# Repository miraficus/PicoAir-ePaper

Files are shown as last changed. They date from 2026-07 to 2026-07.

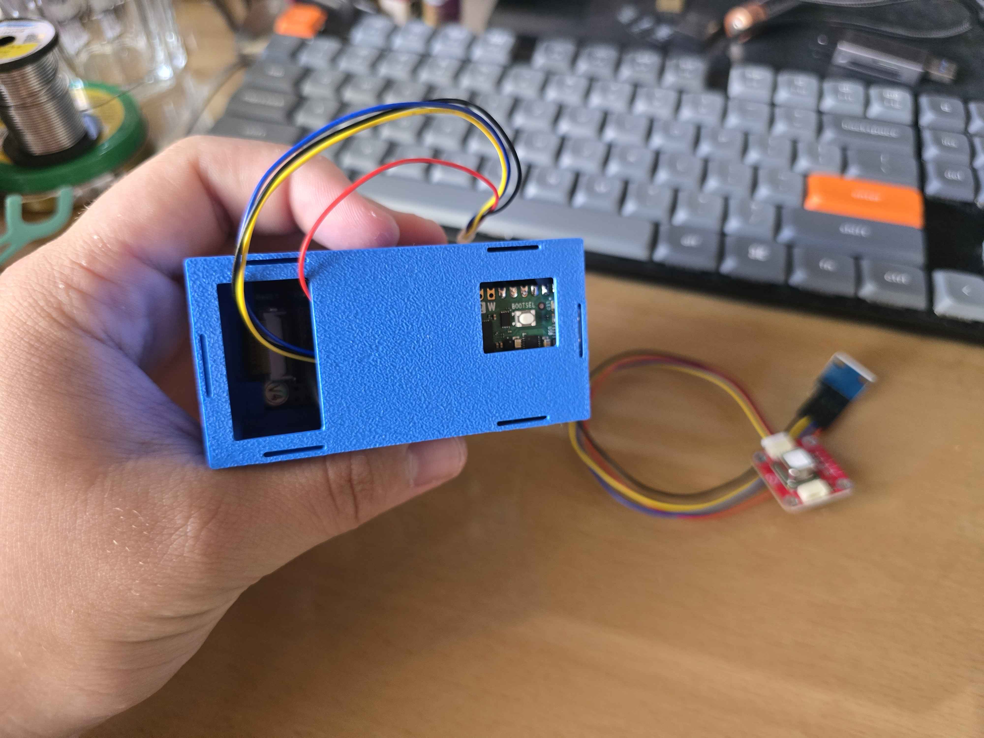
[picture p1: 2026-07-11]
photos/withmiddlecase.jpg

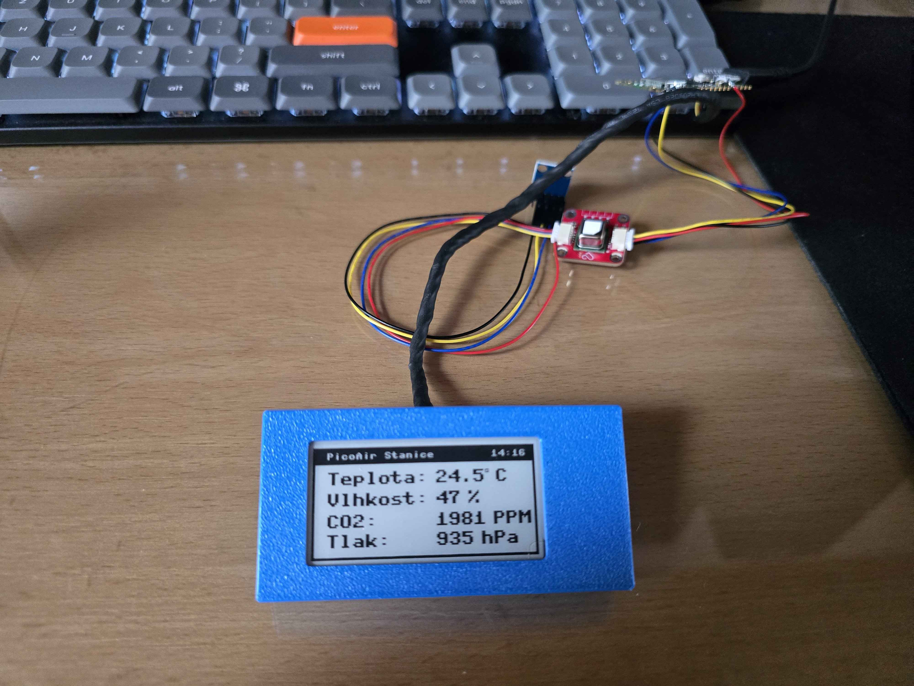
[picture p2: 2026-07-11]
photos/outside.jpg

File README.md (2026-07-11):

# PicoAir-ePaper
[WIP] Pi Pico based device with ePaper display to show temperature, humidity, ppm, time and pressure.

---

# 🍃 PicoAir ePaper Station

Moderní, energeticky úsporná meteostanice a monitor kvality vzduchu v interiéru postavená na mikrokontroléru **Raspberry Pi Pico W**. Stanice měří teplotu, vlhkost, koncentraci CO₂ a atmosférický tlak. Naměřená data zobrazuje na elegantním e-ink (e-paper) displeji a zároveň je v reálném čase odesílá přes Wi-Fi do databáze **InfluxDB** pro vizualizaci v **Grafaně**.

---

## ✨ Hlavní vlastnosti
- **Komplexní měření:** Sledování klíčových parametrů vzduchu (Teplota, Vlhkost, CO₂ v PPM, Tlak v hPa).
- **Sdílená I2C sběrnice:** Efektivní paralelní zapojení více senzorů na piny GP18/GP19.
- **e-Paper Displej:** Nízká spotřeba, perfektní čitelnost na slunci a nativní softwarová rotace obrazu na šířku.
- **Wi-Fi a NTP synchronizace:** Automatické nastavení přesného času z internetu s vestavěnou detekcí a přepínáním letního/zimního času (DST).
- **Direct InfluxDB logování:** Odesílání dat přímo z Pica do databáze pomocí HTTP Line Protocolu bez nutnosti mezistupňů.
- **Úsporný režim:** Kompletní odpojování a hluboký spánek Wi-Fi modulu i displeje mezi měřeními pro šetření baterie.

---

## 🛠️ Hardwarové komponenty
1. **[Raspberry Pi Pico W](https://rpishop.cz/554053/raspberry-pi-pico-2-w/)** (mikrokontrolér s Wi-Fi) [209 CZK]
2. **[Sensirion SCD41](https://www.laskakit.cz/laskakit-scd41-senzor-co2--teploty-a-vlhkosti-vzduchu/)** (fotoakustický senzor CO₂, teploty a vlhkosti) [888 CZK]
3. **[Bosch BMP180](https://www.gme.cz/v/1513747/modul-meteocidlo-s-bmp180)** (senzor barometrického tlaku a teploty) [39 CZK]
4. **[Waveshare e-Paper Displej](https://rpishop.cz/pico-karty/3653-waveshare-213-e-paper-displej-pro-raspberry-pi-pico.html)** (2.13" / 2.9" nebo kompatibilní SPI e-ink) [419 CZK]
5. **[TP4056 Napájecí Modul](https://www.laskakit.cz/nabijecka-li-ion-clanku-tp4056-usb-c/)** Li-Ion / Li-Po baterie + mechanický vypínač (volitelně)

---

## 💾 Software & Firmware
Pro provoz této stanice je vyžadován MicroPython s podporou síťových funkcí. 
- **Doporučený firmware:** [MicroPython pro Raspberry Pi Pico 2 W / Pico W](https://micropython.org/download/RPI_PICO2_W/) (.uf2 soubor)
- **Vývojové prostředí:** VS Codium / VS Code s rozšířením *MicroPico*, případně Thonny IDE.

---

## 🔌 Schéma zapojení (Wiring)

Všechny senzory sdílí jednu hardwarovou sběrnici **I2C1**.

### I2C Senzory (SCD41 & BMP180)
Senzory zapojte paralelně k sobě na následující piny:
| Senzor Pin | Raspberry Pi Pico W Pin | Popis |
| :--- | :--- | :--- |
| **3.3V / VCC** | 3.3V (Pin 36) | Napájení (BMP180 připojte na 3.3V pin, nikoliv VCC!) |
| **GND** | GND | Společná zem |
| **SDA** | GP18 (Pin 24) | Datová linka I2C1 |
| **SCL** | GP19 (Pin 25) | Hodinová linka I2C1 |

### e-Paper Displej (SPI)
| Displej Pin | Raspberry Pi Pico W Pin | Popis |
| :--- | :--- | :--- |
| **BUSY** | GP4 (Pin 6) | Input s PULL_DOWN |
| **RST** | GP1 (Pin 2) | Reset displeje |
| **DC** | GP0 (Pin 1) | Data/Command selection |
| **CS** | GP5 (Pin 7) | Chip Select |
| **SCLK** | GP2 (Pin 4) | SPI Clock |
| **DIN / MOSI** | GP3 (Pin 5) | SPI Master Out |
| **VCC** | 3.3V | Napájení |
| **GND** | GND | Zem |

---

## ⚙️ Softwarová konfigurace (`.env`)

Pro správný běh stanice vytvořte v kořenovém adresáři soubor `.env` (Pico si konfiguraci načte automaticky):

```env
WIFI_SSID="Nazev_Tvoji_Wifi"
WIFI_PASSWORD="Heslo_K_Wifi"
MQTT_ENABLED=1
MQTT_BROKER="IP_Adresa_Tveho_Serveru"
MQTT_LOCATION="Pokoj"
REFRESH_RATE=300
DARK_MODE=0
UNITS="C"
NTP_ADDRESS="time.windows.com"
UTC_TIMEZONE=1
TEXT_TEMPERATURE="Teplota"
TEXT_HUMIDITY="Vlhkost"
TEXT_PPM="PPM"
TEXT_PRESSURE="Tlak"
```

---

## 🖨️ 3D Tisk (OpenSCAD)

Pouzdro je kompletně navrženo v programu **OpenSCAD**.

* **Konstrukce zámků:** V rozích krabičky jsou připraveny otvory s tiskovou tolerancí pro malé magnety z e-cigaret (SYX pody), které drží obě půlky u sebe bez šroubů.
* **Termální management:** Krabička obsahuje vnitřní přepážku, která izoluje senzor SCD41 od tepla generovaného procesorem Pico 2 W.

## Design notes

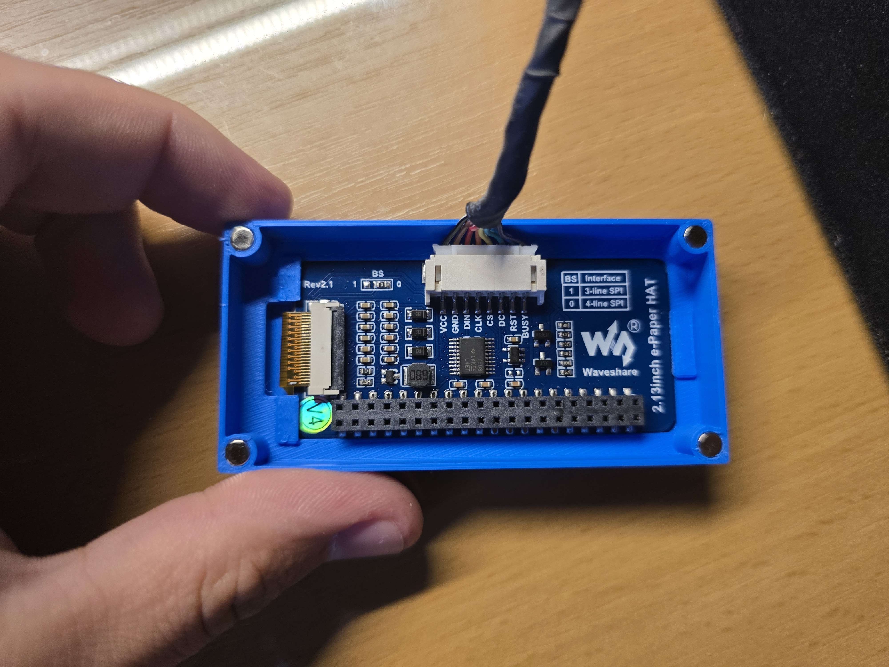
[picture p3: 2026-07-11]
photos/displayinside.jpg

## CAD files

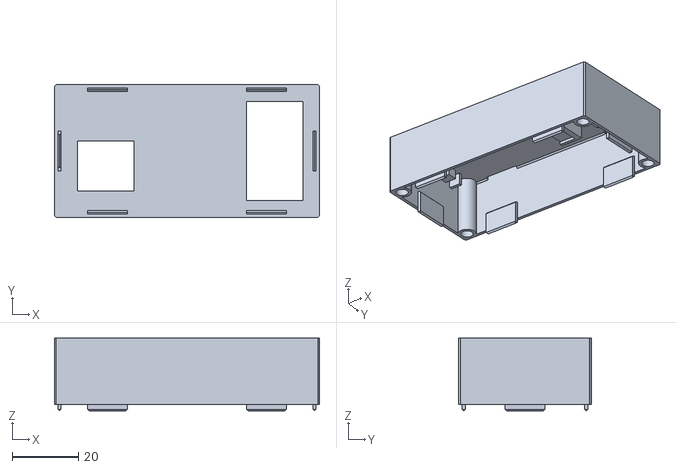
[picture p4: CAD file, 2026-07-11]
case/midcase.stl
80.0 x 40.0 x 22.0

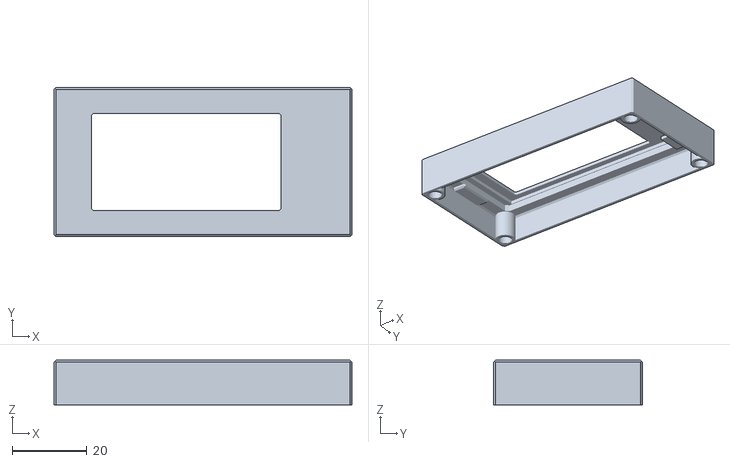
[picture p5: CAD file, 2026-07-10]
case/frontcase.stl
80.0 x 40.0 x 12.0

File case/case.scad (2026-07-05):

echo(version=version());

//Chamfer Library
/* https://github.com/SebiTimeWaster/Chamfers-for-OpenSCAD */
include <Chamfers-for-OpenSCAD/Chamfer.scad>;

    
/* [Customizer] */
// Increase the visual detail
$fn = 100;

module display() {
    color("red")
    translate([0,-0.25,0])
    chamferCube([65.5, 30.5, 2], [[0, 0, 0, 0], [0, 0, 0, 0], [1, 1, 1, 1]], 1);
    
    color("pink")
    translate([2,0,2])
    cube([62,30,1]);
    
    color("blue")
    translate([5,2,3])
    chamferCube([51, 26, 1], [[0, 0, 0, 0], [0, 0, 0, 0], [1, 1, 1, 1]], 0.5);
    
    color("lightblue")
    translate([62,7,0])
    cube([8,16,3]);
}

module casefront() {
    color("white")
    chamferCube([80, 40, 12], [[0, 0, 1, 1], [0, 1, 1, 0], [1, 1, 1, 1]], 0.5);
    
}

module frontcase() {
    difference() {
    casefront();

    translate([5,5,8])
    display();
    
    translate([1,1,0])
    chamferCube([78, 38, 8], [[0, 0, 1, 1], [0, 1, 1, 0], [1, 1, 1, 1]], 0.5);

    }
}  

module displayholds() {
    translate([69,4,7])
    color("lightgreen")
    chamferCube([4, 8, 1], [[1, 0, 0, 0], [0, 0, 0, 1], [0, 1, 0, 0]], 0.5);

    translate([69,28,7])
    color("lightgreen")
    chamferCube([4, 8, 1], [[0, 1, 0, 0], [0, 0, 0, 1], [0, 0, 1, 0]], 0.5);

    translate([1.5,14,7])
    color("lightgreen")
    chamferCube([4, 12, 1], [[1, 1, 0, 0], [0, 0, 0, 1], [0, 1, 1, 0]], 0.5);
}
 
module magnethold() {
    difference() {
        translate([3,3,0])
        color("red")
        cylinder(d=6, h=11);
        
        translate([3,3,0])
        color("pink")
        cylinder(d=4, h=6); 
    }
}

module magnetholds() {
    magnethold();

    translate([74,0,0])
    magnethold();

    translate([0,34,0])
    magnethold();
    
    translate([74,34,0])
    magnethold();    
    


}





 
frontcase();    
displayholds();    
magnetholds();
    
    
    
    

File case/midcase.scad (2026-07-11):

echo(version=version());

//Chamfer Library
/* https://github.com/SebiTimeWaster/Chamfers-for-OpenSCAD */
include <Chamfers-for-OpenSCAD/Chamfer.scad>;

    
/* [Customizer] */
// Increase the visual detail
$fn = 100;


module case() {
    color("white")
    chamferCube([80, 40, 20], [[0, 0, 0, 0], [0, 0, 0, 0], [1, 1, 1, 1]], 0.5);
}

module cutcase() {
    difference() {
        case();
        
        translate([1,1,0])
        chamferCube([78, 38, 19], [[0, 0, 1, 1], [0, 1, 1, 0], [1, 1, 1, 1]], 0.5);
    
        color("grey")
        translate([58,5,18])
        cube([17,30,3]); 
        
        color("grey")
        translate([7,8,18])
        cube([17,15,3]); 
    }   
}  
 
module magnethold() {
    difference() {
        translate([3,3,0])
        color("red")
        cylinder(d=6, h=19);
        
        translate([3,3,0])
        color("pink")
        cylinder(d=4, h=7); 
    }
}

module magnetholds() {
    magnethold();

    translate([74,0,0])
    magnethold();

    translate([0,34,0])
    magnethold();
    
    translate([74,34,0])
    magnethold();    
}

module caseholds() {
    translate([1,14,-2])
    color("lightgreen")
    chamferCube([1, 12, 8], [[1, 1, 0, 0], [1, 0, 1, 1], [0, 0, 0, 0]], 0.5);

    translate([78,14,-2])
    color("lightgreen")
    chamferCube([1, 12, 8], [[1, 1, 0, 0], [1, 1, 0, 1], [0, 0, 0, 0]], 0.5);

    rotate([0,0,90])
    translate([1,-70,-2])
    color("lightgreen")
    chamferCube([1, 12, 8], [[1, 1, 0, 0], [1, 0, 1, 1], [0, 0, 0, 0]], 0.5);
 
    rotate([0,0,90])
    translate([1,-22,-2])
    color("lightgreen")
    chamferCube([1, 12, 8], [[1, 1, 0, 0], [1, 0, 1, 1], [0, 0, 0, 0]], 0.5);
  
    rotate([0,0,270])
    translate([-39,10,-2])
    color("lightgreen")
    chamferCube([1, 12, 8], [[1, 1, 0, 0], [1, 0, 1, 1], [0, 0, 0, 0]], 0.5);
   
    rotate([0,0,270])
    translate([-39,58,-2])
    color("lightgreen")
    chamferCube([1, 12, 8], [[1, 1, 0, 0], [1, 0, 1, 1], [0, 0, 0, 0]], 0.5);
}

module caseholdsholes() {
    difference() {
        cutcase();
        
        translate([0,0,16])
        color("blue")
        caseholds();
    }     
}

module pico() {
    translate([1,9.5,15])
    cube([51.2,21,1]);

    translate([-1,16,15.5])
    color("red")
    chamferCube([8, 8, 3], [[1, 1, 0, 0], [0, 0, 0, 0], [0, 0, 0, 0]], 1.5);

    translate([1,15,16])
    color("pink")
    cube([6,10,3]);
    
    color("green")
    translate([46.2,17.5,16])
    cube([6,5,2]);

    color("white")
    translate([1,9.5,16])
    cube([5,2,3]);

    color("white")
    translate([1,28.5,16])
    cube([5,2,3]);
    
}

module picoholder() {
    color("lightblue")
    translate([46.2,8.5,15])
    cube([8,23,4]);

    color("lightblue")
    translate([0,8.5,15])
    cube([5,23,4]);
}

difference() {
    picoholder();
    pico();
}

difference() {
    caseholdsholes();
    pico();
}



//picoholder();
//pico();        
magnetholds();
caseholds();    
//caseholdsholes();     
    
    

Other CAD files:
case/frontcase.scad

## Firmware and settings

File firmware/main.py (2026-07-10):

import time
from machine import Pin, SPI, ADC, I2C
import framebuf
import network
import socket
import struct

print("[START] Spouštím kompletně vyčištěný program v nekonečné smyčce...")

def load_env_config():
    config = {
        "DARK_MODE": "0",
        "UNITS": "C",
        "REFRESH_RATE": "60",
        "TEXT_TEMPERATURE": "Teplota:",
        "TEXT_HUMIDITY": "Vlhkost:",
        "TEXT_PPM": "PPM:",
        "TEXT_PRESSURE": "Tlak:",
        "WIFI_SSID": "",
        "WIFI_PASSWORD": "",
        "NTP_ADDRESS": "pool.ntp.org",
        "UTC_TIMEZONE": "1",
        "MQTT_ENABLED": "0",
        "MQTT_BROKER": "",
        "MQTT_PORT": "1883",
        "MQTT_LOCATION": "pokoj"
    }
    try:
        with open(".env", "r") as f:
            for line in f:
                line = line.strip()
                if not line or line.startswith("#"):
                    continue
                if "=" in line:
                    key, value = line.split("=", 1)
                    config[key.strip()] = value.strip().strip('"').strip("'")
    except Exception:
        pass
    return config

# Načteme konfiguraci do globálních proměnných
env = load_env_config()

DARK_MODE = int(env["DARK_MODE"])
if DARK_MODE == 1:
    COLOR_BG = 0  
    COLOR_FG = 1  
else:
    COLOR_BG = 1  
    COLOR_FG = 0  

USER_UNITS = env["UNITS"].upper()

# Načtení lokalizovaných textů
TXT_TEMP = env["TEXT_TEMPERATURE"] + ":" if not env["TEXT_TEMPERATURE"].endswith(":") else env["TEXT_TEMPERATURE"]
TXT_HUMI = env["TEXT_HUMIDITY"] + ":" if not env["TEXT_HUMIDITY"].endswith(":") else env["TEXT_HUMIDITY"]
TXT_PPM  = env["TEXT_PPM"] + ":" if not env["TEXT_PPM"].endswith(":") else env["TEXT_PPM"]
TXT_PRESSURE = env["TEXT_PRESSURE"] + ":" if not env["TEXT_PRESSURE"].endswith(":") else env["TEXT_PRESSURE"]

try:
    REFRESH_RATE = int(env["REFRESH_RATE"])
except (KeyError, ValueError):
    REFRESH_RATE = 60

if REFRESH_RATE < 20:
    REFRESH_RATE = 20

# Načtení síťové konfigurace
MQTT_ENABLED = int(env.get("MQTT_ENABLED", "0"))
MQTT_BROKER = env.get("MQTT_BROKER", "")
MQTT_PORT = int(env.get("MQTT_PORT", "1883"))
MQTT_LOCATION = env.get("MQTT_LOCATION", "unknown")


# === AUTOMATICKÝ TEST A INICIALIZACE I2C PRO SCD41 ===
SCD41_ADDR = 0x62
BMP180_ADDR = 0x77
i2c = None
scd41_funkcni = False
bmp180_funkcni = False

bmp_calib = {}

def scd41_send_command(cmd):
    if not scd41_funkcni or i2c is None: return
    buf = bytes([cmd >> 8, cmd & 0xFF])
    i2c.writeto(SCD41_ADDR, buf)
    time.sleep_ms(10)

def init_i2c_scd41_bmp180():
    global i2c, scd41_funkcni, bmp180_funkcni, bmp_calib
    print("\n--- [TEST] Inicializace I2C senzorů na pinech GP18/GP19 ---")
    
    try:
        i2c = I2C(1, scl=Pin(19), sda=Pin(18), freq=100000)
        scan_results = i2c.scan()
        
        # Inicializace SCD41
        if SCD41_ADDR in scan_results:
            scd41_funkcni = True
            print("[SCD41] Senzor úspěšně nalezen a komunikuje!")
            scd41_send_command(0x3F86)
            time.sleep_ms(500)
            scd41_send_command(0x21B1)
            print("[SCD41] Měření nastartováno.")
        else:
            print("[⚠️ VAROVÁNÍ] SCD41 neodpověděl.")
            scd41_funkcni = False

        # Inicializace a načtení kalibrace BMP180
        if BMP180_ADDR in scan_results:
            bmp_calib["AC1"] = bmp180_read_int(0xAA)
            bmp_calib["AC2"] = bmp180_read_int(0xAC)
            bmp_calib["AC3"] = bmp180_read_int(0xAE)
            bmp_calib["AC4"] = bmp180_read_uint(0xB0)
            bmp_calib["AC5"] = bmp180_read_uint(0xB2)
            bmp_calib["AC6"] = bmp180_read_uint(0xB4)
            bmp_calib["B1"]  = bmp180_read_int(0xB6)
            bmp_calib["B2"]  = bmp180_read_int(0xB8)
            bmp_calib["MB"]  = bmp180_read_int(0xBA)
            bmp_calib["MC"]  = bmp180_read_int(0xBC)
            bmp_calib["MD"]  = bmp180_read_int(0xBD)
            bmp180_funkcni = True
            print("[BMP180] Senzor úspěšně nalezen a nakalibrován!")
        else:
            print("[⚠️ VAROVÁNÍ] BMP180 neodpověděl.")
            bmp180_funkcni = False
            
        if scd41_funkcni:
            time.sleep(5)
            
    except Exception as e:
        print("[⚠️ CHYBA] Selhala inicializace I2C sběrnice:", e)
        scd41_funkcni = False
        bmp180_funkcni = False

def read_scd41():
    if not scd41_funkcni or i2c is None:
        return None, None, None
    co2, temp, humi = None, None, None
    try:
        scd41_send_command(0xEC05)
        time.sleep_ms(50)
        
        # Čteme 9 bajtů (CO2 + CRC, Temp + CRC, Humi + CRC)
        data = i2c.readfrom(SCD41_ADDR, 9)
        
        co2 = (data[0] << 8) | data[1]
        
        temp_word = (data[3] << 8) | data[4]
        temp = -45.0 + 175.0 * temp_word / 65536.0
        
        humi_word = (data[6] << 8) | data[7]
        humi = 100.0 * humi_word / 65536.0
    except Exception as e:
        print("[SCD41] Nepodařilo se přečíst data:", e)
    return co2, temp, humi


def bmp180_read_int(reg):
    data = i2c.readfrom_mem(BMP180_ADDR, reg, 2)
    val = (data[0] << 8) | data[1]
    return val - 65536 if val >= 32768 else val

def bmp180_read_uint(reg):
    data = i2c.readfrom_mem(BMP180_ADDR, reg, 2)
    return (data[0] << 8) | data[1]

def read_bmp180():
    if not bmp180_funkcni or i2c is None:
        return None
    try:
        # Načtení raw teploty (nutné pro kompenzaci tlaku)
        i2c.writeto_mem(BMP180_ADDR, 0xF4, b'\x2E')
        time.sleep_ms(5)
        ut = bmp180_read_uint(0xF6)
        
        # Načtení raw tlaku
        i2c.writeto_mem(BMP180_ADDR, 0xF4, b'\x34')
        time.sleep_ms(5)
        up = bmp180_read_uint(0xF6)
        
        # Matematická kompenzace podle datasheetu Bosch
        x1 = (ut - bmp_calib["AC6"]) * bmp_calib["AC5"] >> 15
        x2 = (bmp_calib["MC"] << 11) // (x1 + bmp_calib["MD"])
        b5 = x1 + x2
        
        b6 = b5 - 4000
        x1 = (bmp_calib["B2"] * (b6 * b6 >> 12)) >> 11
        x2 = bmp_calib["AC2"] * b6 >> 11
        x3 = x1 + x2
        b3 = (((bmp_calib["AC1"] * 4 + x3) << 0) + 2) >> 2
        
        x1 = bmp_calib["AC3"] * b6 >> 13
        x2 = (bmp_calib["B1"] * (b6 * b6 >> 12)) >> 16
        x3 = ((x1 + x2) + 2) >> 2
        b4 = (bmp_calib["AC4"] * (x3 + 32768)) >> 15
        b7 = (up - b3) * 50000
        
        p = (b7 * 2) // b4 if b7 < 0x80000000 else (b7 // b4) * 2
        x1 = (p >> 8) * (p >> 8)
        x1 = (x1 * 3038) >> 16
        x2 = (-7357 * p) >> 16
        return (p + ((x1 + x2 + 3791) >> 4)) / 100.0
    except Exception as e:
        print("[BMP180] Chyba při čtení tlaku:", e)
        return None

# Proměnné pro uchování synchronizovaného času
base_timestamp = 0
base_ticks = 0
time_synchronized = False

def connect_wifi_and_sync_time():
    global base_timestamp, base_ticks, time_synchronized
    ssid = env["WIFI_SSID"]
    password = env["WIFI_PASSWORD"]
    ntp_server = env["NTP_ADDRESS"]
    
    if not ssid:
        print("[WIFI] V .env chybí název Wi-Fi, spouštím bez internetu.")
        return None

    print("[WIFI] Čekám na stabilizaci napájení...")
    time.sleep(2)

    wlan = network.WLAN(network.STA_IF)
    
    print("[WIFI] Resetuji Wi-Fi modul...")
    wlan.active(False)
    time.sleep(1)
    wlan.active(True)
    time.sleep(1) 
    
    print("[WIFI] Připojuji se k: {}".format(ssid))
    wlan.connect(ssid, password)
    
    max_wait = 20
    while max_wait > 0 and not wlan.isconnected():
        max_wait -= 1
        time.sleep(1)
        print(".")
        
    if wlan.isconnected():
        print("\n[WIFI] Úspěšně připojeno! IP:", wlan.ifconfig()[0])
        print("[NTP] Stahuji čas z: {}".format(ntp_server))
        
        try:
            NTP_QUERY = bytearray(48)
            NTP_QUERY[0] = 0x1B
            addr = socket.getaddrinfo(ntp_server, 123)[0][-1]
            s = socket.socket(socket.AF_INET, socket.SOCK_DGRAM)
            s.settimeout(5)
            s.sendto(NTP_QUERY, addr)
            msg, address = s.recvfrom(48)
            s.close()
            
            val = struct.unpack("!I", msg[40:44])[0]
            NTP_DELTA = 2208988800
            timestamp_utc = val - NTP_DELTA
            
            try:
                base_tz = int(env.get("UTC_TIMEZONE", 1))
            except ValueError:
                base_tz = 1

            tm = time.localtime(timestamp_utc)
            year, month, day, hour = tm[0], tm[1], tm[2], tm[3]
            
            mar_sunday = 31 - (time.localtime(time.mktime((year, 3, 31, 1, 0, 0, 0, 0)))[6])
            oct_sunday = 31 - (time.localtime(time.mktime((year, 10, 31, 1, 0, 0, 0, 0)))[6])
            
            is_dst = False
            if 3 < month < 10:
                is_dst = True
            elif month == 3:
                if day > mar_sunday or (day == mar_sunday and hour >= 1):
                    is_dst = True
            elif month == 10:
                if day < oct_sunday or (day == oct_sunday and hour < 1):
                    is_dst = True

            final_tz = base_tz + (1 if is_dst else 0)
            TIMEZONE_OFFSET = final_tz * 3600
            
            base_timestamp = timestamp_utc + TIMEZONE_OFFSET
            base_ticks = time.ticks_ms()
            time_synchronized = True
            
            print("[NTP] Synchronizováno. Datum: {}.{}.{}, Automatický DST: {}".format(day, month, year, "ANO (Letní)" if is_dst else "NE (Zimní)"))
        except Exception as e:
            print("[NTP] Chyba synchronizace času:", e)      
    else:
        print("\n[WIFI] Nepodařilo se připojit k Wi-Fi.")

    return wlan

def get_current_time_str():
    if not time_synchronized:
        return "--:--"
    elapsed_ms = time.ticks_diff(time.ticks_ms(), base_ticks)
    current_timestamp = base_timestamp + (elapsed_ms // 1000)
    local_time = time.localtime(current_timestamp)
    hours = "{:02d}".format(local_time[3])
    minutes = "{:02d}".format(local_time[4])
    return "{}:{}".format(hours, minutes)


class EPD_Landscape_Fix:
    def __init__(self, spi, cs, dc, rst, busy):
        self.spi = spi
        self.cs = cs
        self.dc = dc
        self.rst = rst
        self.busy = busy
        self.buffer_size = 4000 

    def digital_write(self, pin, value):
        pin.value(value)

    def digital_read(self, pin):
        return pin.value()

    def delay_ms(self, delaytime):
        time.sleep_ms(delaytime)

    def send_command(self, command):
        self.digital_write(self.dc, 0)
        self.digital_write(self.cs, 0)
        self.spi.write(bytearray([command]))
        self.digital_write(self.cs, 1)

    def send_data(self, data):
        self.digital_write(self.dc, 1)
        self.digital_write(self.cs, 0)
        self.spi.write(bytearray([data]))
        self.digital_write(self.cs, 1)

    def wait_until_idle(self):
        while(self.digital_read(self.busy) == 1):
            self.delay_ms(50)

    def init(self):
        self.reset()
        self.wait_until_idle()
        self.send_command(0x12) 
        self.wait_until_idle()
        self.send_command(0x01) 
        self.send_data(0xF9)
        self.send_data(0x00)
        self.send_data(0x00)
        self.send_command(0x11) 
        self.send_data(0x03) 
        self.send_command(0x44) 
        self.send_data(0x00)
        self.send_data(0x0F) 
        self.send_command(0x45) 
        self.send_data(0x00)
        self.send_data(0x00)
        self.send_data(0xF9) 
        self.send_data(0x00)
        self.send_command(0x3C) 
        self.send_data(0x05)
        self.send_command(0x18) 
        self.send_data(0x80)
        self.set_cursor(0, 0)
        self.wait_until_idle()

    def reset(self):
        self.digital_write(self.rst, 1)
        self.delay_ms(200)
        self.digital_write(self.rst, 0)
        self.delay_ms(10)
        self.digital_write(self.rst, 1)
        self.delay_ms(200)

    def set_cursor(self, x, y):
        self.send_command(0x4E) 
        self.send_data(x & 0xFF)
        self.send_command(0x4F) 
        self.send_data(y & 0xFF)
        self.send_data((y >> 8) & 0xFF)

    def display_frame(self):
        self.send_command(0x22)
        self.send_data(0xF7) 
        self.send_command(0x20)
        self.wait_until_idle()

    def set_frame_memory(self, image):
        self.set_cursor(0, 0)
        self.send_command(0x24) 
        self.digital_write(self.dc, 1)
        self.digital_write(self.cs, 0)
        self.spi.write(image)
        self.digital_write(self.cs, 1)

    def clear_frame_memory(self, color):
        self.set_cursor(0, 0)
        self.send_command(0x24)
        self.digital_write(self.dc, 1)
        self.digital_write(self.cs, 0)
        self.spi.write(bytes([color] * self.buffer_size))
        self.digital_write(self.cs, 1)

    def sleep(self):
        self.send_command(0x10)
        self.send_data(0x01)

# === KONFIGURACE HARDWARU ===
sck_pin = Pin(2)
mosi_pin = Pin(3)
cs_pin = Pin(5, Pin.OUT)
dc_pin = Pin(0, Pin.OUT)
rst_pin = Pin(1, Pin.OUT)
busy_pin = Pin(4, Pin.IN, Pin.PULL_DOWN) 

print("[1] Inicializuji SPI...")
spi = SPI(0, baudrate=2000000, polarity=0, phase=0, sck=sck_pin, mosi=mosi_pin)

print("[2] Vytvářím objekt displeje...")
epd = EPD_Landscape_Fix(spi, cs_pin, dc_pin, rst_pin, busy_pin)

adc_temp = ADC(4)

def get_cpu_temp():
    raw = adc_temp.read_u16()
    voltage = raw * 3.3 / 65535
    temperature_c = 27 - (voltage - 0.706) / 0.001721
    if USER_UNITS == "F":
        temperature_f = (temperature_c * 9 / 5) + 32
        return round(temperature_f, 1)
    else:
        return round(temperature_c, 1)

WIDTH_LANDSCAPE = 256
HEIGHT_LANDSCAPE = 122

draw_buf = bytearray(WIDTH_LANDSCAPE * HEIGHT_LANDSCAPE // 8)
fb_landscape = framebuf.FrameBuffer(draw_buf, WIDTH_LANDSCAPE, HEIGHT_LANDSCAPE, framebuf.MONO_HLSB)

DISP_WIDTH = 128
DISP_HEIGHT = 250
display_buf = bytearray(DISP_WIDTH * DISP_HEIGHT // 8)
fb_display = framebuf.FrameBuffer(display_buf, DISP_WIDTH, DISP_HEIGHT, framebuf.MONO_HLSB)

def text_large(text, start_x, start_y, color=0):
    current_x = start_x
    char_buf = bytearray(8 * 8 // 8)
    char_fb = framebuf.FrameBuffer(char_buf, 8, 8, framebuf.MONO_HLSB)
    for char in text:
        if color == 1:
            char_fb.fill(0)
            char_fb.text(char, 0, 0, 1)
        else:
            char_fb.fill(1)
            char_fb.text(char, 0, 0, 0)
        for x in range(8):
            for y in range(8):
                if char_fb.pixel(x, y) == color:
                    target_x = current_x + (x * 2)
                    target_y = start_y + (y * 2)
                    fb_landscape.pixel(target_x, target_y, color)
                    fb_landscape.pixel(target_x + 1, target_y, color)
                    fb_landscape.pixel(target_x, target_y + 1, color)
                    fb_landscape.pixel(target_x + 1, target_y + 1, color)
        if char == " ":
            current_x += 8
        else:
            current_x += 14

# Spustíme automatický vyhledávací test senzoru
init_i2c_scd41_bmp180()

# === HLAVNÍ SMYČKA PROGRAMU ===
while True:
    print("\n--- Spouštím novou aktualizaci stanice ---")
    
    # 1. VYČTEME DATA ZE SENZORU SCD41 (Pokud prošel testem)
    co2, s_temp, s_humi = read_scd41()
    air_pressure = read_bmp180()
    
    # Formátování textů pro e-ink (pokud čtení selže nebo senzor není, hodí se pomlčky)
    if s_temp is not None:
        if USER_UNITS == "F":
            s_temp = (s_temp * 9 / 5) + 32
        temp_value_str = "{:.1f}".format(s_temp)
    else:
        temp_value_str = "--.-"
        
    humi_value_str = "{:.0f} %".format(s_humi) if s_humi is not None else "-- %"
    co2_value_str = "{:d} PPM".format(co2) if co2 is not None else "----"
    temp_unit_str = " {}".format(USER_UNITS)
    pressure_value_str = "{:.0f} hPa".format(air_pressure) if air_pressure is not None else "---- hPa"

    # 2. VYKRESLÍME DATA NA DISPLEJ
    print("[3] Volám epd.init()...")
    epd.init()

    print("[4] Mažu displej...")
    epd.clear_frame_memory(0xFF)
    epd.display_frame()

    fb_landscape.fill(COLOR_BG)
    fb_display.fill(1)

    fb_landscape.rect(0, 0, 250, 121, COLOR_FG)
    fb_landscape.rect(1, 1, 248, 119, COLOR_FG)
    fb_landscape.rect(2, 2, 246, 117, COLOR_FG)

    current_time_str = get_current_time_str()
    fb_landscape.fill_rect(3, 3, 244, 16, COLOR_FG)
    fb_landscape.text("PicoAir Stanice", 15, 6, COLOR_BG)
    fb_landscape.text(current_time_str, 200, 6, COLOR_BG)

    # Teplota ze senzoru
    text_large(TXT_TEMP, 15, 27, COLOR_FG)
    text_large(temp_value_str, 135, 27, COLOR_FG)

    degree_x = 135 + (len(temp_value_str) * 14)
    fb_landscape.rect(degree_x + 2, 27, 4, 4, COLOR_FG)
    text_large(temp_unit_str, degree_x + 4, 27, COLOR_FG)

    # Vlhkost ze senzoru
    text_large(TXT_HUMI, 15, 50, COLOR_FG)
    text_large(humi_value_str, 135, 50, COLOR_FG) 

    # CO2 ze senzoru
    text_large(TXT_PPM, 15, 73, COLOR_FG)
    text_large(co2_value_str, 135, 73, COLOR_FG)

    # Tlak (SCD41 nemá, zůstávají pomlčky)
    text_large(TXT_PRESSURE, 15, 94, COLOR_FG)
    text_large(pressure_value_str, 135, 94, COLOR_FG)   

    print("Přetáčím pixely do nativní orientace...")
    for x in range(WIDTH_LANDSCAPE):
        for y in range(HEIGHT_LANDSCAPE):
            pixel = fb_landscape.pixel(x, y)
            new_x = (DISP_WIDTH - 1 - y) - 7
            new_y = x
            if 0 <= new_x < DISP_WIDTH:
                fb_display.pixel(new_x, new_y, pixel)

    print("[5] Posílám otočená data na displej...")
    epd.set_frame_memory(display_buf)
    epd.display_frame()

    print("[6] Ukládám displej ke spánku.")
    epd.sleep()
    
    # 3. ZAPNEME WI-FI SÍT PRO SYNC ČASU A INFLUX
    wlan = connect_wifi_and_sync_time()
    
    # 4. ODESÍLÁNÍ DAT PŘÍMO DO INFLUXDB (Pouze pokud máme data ze senzoru)
    if MQTT_ENABLED == 1 and MQTT_BROKER and (scd41_funkcni or bmp180_funkcni):
        if wlan and wlan.isconnected():
            print("[INFLUX] Odesílám data přímo do databáze...")
            try:
                url_ip = MQTT_BROKER
                port = 8086
                
                fields = []
                if s_temp is not None: fields.append("teplota={:.2f}".format(s_temp))
                if s_humi is not None: fields.append("vlhkost={:.2f}".format(s_humi))
                if co2 is not None: fields.append("co2={:d}".format(co2))
                if air_pressure is not None: fields.append("tlak={:.2f}".format(air_pressure))
                
                payload = "pocasi,lokace={} {}\n".format(MQTT_LOCATION, ",".join(fields))
                
                s = socket.socket()
                addr = socket.getaddrinfo(url_ip, port)[0][-1]
                s.connect(addr)
                
                http_req = (
                    "POST /write?db=meteostanice HTTP/1.1\r\n"
                    "Host: {}:{}\r\n"
                    "Content-Length: {}\r\n"
                    "Content-Type: text/plain\r\n"
                    "\r\n"
                    "{}"
                ).format(url_ip, port, len(payload), payload)
                
                s.write(http_req.encode('utf-8'))
                response = s.read(64).decode('utf-8')
                s.close()
                
                if "204" in response:
                    print("[INFLUX] Všechna data úspěšně zapsána do InfluxDB!")
                else:
                    print("[INFLUX] Server odpověděl jinak:", response.split("\r\n")[0])
                    
            except Exception as e:
                print("[INFLUX] Selhalo odeslání do InfluxDB:", e)
        else:
            print("[INFLUX] Wi-Fi není připojena, data neodeslána.")
            
    # 5. KOMPLETNÍ VYPNUTÍ WI-FI PŘED SPÁNKEM
    if wlan:
        wlan.active(False)
    print("[SYSTEM] Wi-Fi modul kompletně uspán.")
    
    print("[ČEKÁNÍ] Hotovo. Za {} sekund proběhne další měření...".format(REFRESH_RATE))
    time.sleep(REFRESH_RATE)

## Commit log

2026-06-19 Enhance README with project overview and setup guide
    Expanded README.md with project details, features, BOM, pinout, and setup instructions.
2026-06-22 Add MicroPython firmware and project configs
    Add a new firmware folder with main.py implementing an EPD_Direct driver and demo for a 128x250 e-paper display (Pico/SPI). Include project metadata and editor configs (.micropico, .vscode/extensions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
2026-06-22 EPD driver: landscape support and buffer refactor
    Refactor the e-paper driver and main app to support landscape drawing and proper frame buffering. Renamed EPD_Direct to EPD_Landscape_Fix, removed unused width/height fields, added fixed buffer_size (4000 bytes), set_cursor helper and reduced BUSY poll delay. Switched to bulk SPI writes for frame/clear operations, lowered SPI baudrate comment for stability, and updated initialization sequence/comments. Main now builds a landscape framebuffer, rotates/centers pixels into a 128x250 display buffer and sends it via set_frame_memory; minor log message and wording changes included.
    [main.py]
2026-06-22 Add CPU temp, large-text renderer & UI
    Initialize internal ADC temperature sensor (ADC(4)) and add get_cpu_temp() using RP2 sensor formula to display CPU temperature. Implement text_large() to render 2x-scaled text with optional color (black/white) by drawing into a temporary framebuffer and blitting 2x2 pixels into the landscape buffer. Update landscape framebuffer/layout: use 256x122 buffer, draw a 3-pixel thick frame, add an inverted black top bar with white title/version, and place large placeholder fields for temperature, humidity, PPM and time (temperature pulled from get_cpu_temp()). Keep the original rotation/transfer to native display but apply a horizontal offset to better center t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
    [main.py]
2026-06-22 Load .env, add unit/localization and UI refactor
    Add .env.example and implement runtime .env loading in main.py to configure dark mode, units and localized labels. Update CPU temperature reading to respect C/F units, and expose USER_UNITS and TXT_*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
2026-06-22 Refactor display flow and add main update loop
    Introduce an infinite main loop that reinitializes the e-paper display, clears it and updates content every 60s instead of running once. Refactor buffering and text rendering: define DISP_WIDTH/DISP_HEIGHT earlier, create fb_display/display_buf up front, and simplify/enhance text_large (2x scaling with tightened spacing). Move epd.init()/clear/display into the loop, preserve pixel rotation transfer, and remove stale/duplicated initialization and commented lines. Minor cleanups: update startup print message, small comment and ADC initialization tweaks, and tidy up display_frame send_data line.
    [main.py]
2026-06-23 Add REFRESH_RATE env and enforce min interval
    Introduce REFRESH_RATE configurable parameter (default 60s) in .env.example and main.py. Parse REFRESH_RATE from env with fallback to 60 on missing/invalid values, enforce a safety minimum of 20 seconds, and use the value for the loop sleep/print message instead of the hardcoded 60s.
    [main.py]
2026-06-24 Add Wi-Fi/NTP time sync and env vars
    Introduce Wi-Fi and NTP synchronization: new .env keys (WIFI_SSID, WIFI_PASSWORD, NTP_ADDRESS, UTC_TIMEZONE) and TEXT_PRESSURE in .env.example. Implement connect_wifi_and_sync_time(), get_current_time_str(), DST-aware timezone offset and lightweight NTP client; call sync at startup and use synchronized time in the UI. Improve .env parsing to strip surrounding quotes, move/import ADC and other modules, and adjust display/layout: update large-text spacing and X coordinates, replace static time/pressure UI elements with dynamic placeholders. Also minor driver/formatting cleanup in EPD class and ensure a minimum REFRESH_RATE.
    [main.py]
2026-07-05 Add MQTT/Influx and Wi‑Fi/NTP improvements
    Update firmware configuration and main logic: extend firmware/.env.example with MQTT variables and update parsing in load_env_config. Add a MojeMQTT helper class (basic CONNECT/PUBLISH/DISCONNECT) and MQTT/Influx write path: after drawing the display the device now connects Wi‑Fi, syncs NTP, and optionally posts temperature to InfluxDB (HTTP write) when MQTT_ENABLED. Improve Wi‑Fi startup (stabilization pause, hard reset, longer waits), refactor NTP/DST handling, defer network use until after display update, and disable Wi‑Fi before sleeping. Changes are in firmware/.env.example and firmware/main.py.
    [main.py]
2026-07-05 Add SCD41 sensor integration
    Integrate SCD41 CO2/temperature/humidity sensor via I2C on pins GP18/GP19. Removes unused MojeMQTT class. Displays live sensor readings on e-ink display and sends all measurements (CO2, temperature, 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
2026-07-05 Add OpenSCAD case design
    Add case.scad file with 3D model definition for the PicoAir ePaper display case. The design includes a front case shell with chamfered edges, display opening, and display hold mechanisms. Requires th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
    [case.scad]
2026-07-05 Add magnet holds and fix displayholds formatting
    Added magnethold() and magnetholds() modules to define 4 magnet hold positions at the corners. Fixed indentation in displayholds() module and adjusted chamfer parameters for two of the display hold cubes. Updated module instantiation to include magnetholds().
    [case.scad]
2026-07-05 Add PPM unit to CO2 display
    Updated CO2 value formatting to include PPM unit in the display string. Also updated the environment example label from 'PPM' to 'CO2' for consistency. Added 3D printable case model file.
    [case.stl]
2026-07-10 Add BMP180 pressure sensor support
    Integrate BMP180 pressure sensor alongside existing SCD41 sensor. Adds initialization, calibration reading, and pressure measurement functions. Updates main loop to read and display pressure values. Modifies InfluxDB payload to include pressure data and gracefully handle missing individual measurements. Enables data transmission if either sensor is functional.
    [main.py]
2026-07-10 Split case into front and middle components
    Refactor the case design into separate front and middle modules. The original case files are renamed to frontcase to represent the front component, and a new midcase module is added with the middle s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
    [case.stl, frontcase.scad, frontcase.stl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]
2026-07-10 Refactor midcase design with Pico holder modules
    Add new Pico microcontroller component holder modules (pico, picoholder, caseholdsholes) with proper positioning and visual representation. Refactor cutcase() with improved indentation and geometry. 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
    [midcase.scad, midcase.stl]
2026-07-10 Bootselect Window
    [midcase.scad, midcase.stl]
2026-07-11 Adjust midcase dimensions and add photos
    Increase magnet pocket depth by 1mm (cylinder height 18→19) and shift the two case-hold features 1mm along Y (translate y 15→14) to improve magnet fit and alignment. Regenerated midcase.stl and added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
    [midcase.scad, midcase.stl]
